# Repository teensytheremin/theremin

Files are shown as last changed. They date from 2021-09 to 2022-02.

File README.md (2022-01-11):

# Teensy Theremin

Teensy 4.1 MCU based Digital Theremin

This project is aimed to design of simple but good DIY digital [theremin](https://en.wikipedia.org/wiki/Theremin) based on microcontroller and FPGAs.

Cabinet render

Project's documentation is available on [Github Pages](https://teensytheremin.github.io/theremin/)

Component placement

PCB render

## Licensing

This is open source open hardware project.

You can freely build device using instructions for personal usage, but cannot sell it.

Firmware is licensed under GPL v2 license.

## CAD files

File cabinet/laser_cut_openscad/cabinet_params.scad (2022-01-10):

pcb_width=60.96;
pcb_length=210.82;
pcb_thickness=1.6;

cabinet_length=420;
cabinet_height=44;

panel_width=120;
panel_height=cabinet_height*0.65;
panel_rounding=panel_height/2-1;
panel_thickness=1;
panel_extra_space=0.3;
front_panel_offset_y = -2;
rear_panel_offset_y = -2;

mic_stand_mount_height = 18.288; // 0.72

cabinet_width=pcb_width + panel_thickness*2 + panel_extra_space*2;

sheet_thickness=4;

edge_extra=5;
edge_rounding=3;

ray_correction=-0.1;


// destance between volume antenna ends
volume_antenna_mount_delta=87;


// laser cut parts mounting spikes dimensions
spike_width = 16;
spike_height = sheet_thickness + edge_rounding + 0.5;


pcb_dy = -12;
pcb_mount_h = cabinet_height/2 + pcb_dy; // - pcb_thickness;
pcb_mount_offset = panel_thickness + panel_extra_space;
pcb_mount_width = spike_width + 10;


holder_angle=30;
holder_front_extra=50;


inductor_mount_wall_dist = 1;

inductor_frame_d = 32;
inductor_frame_internal_d = 20;
inductor_mount_spring_thickness = 2.2;
inductor_mount_spring_angle = 13;

volume_inductor_offset = 44;
volume_inductor_winding_len=45;

pitch_inductor_offset = inductor_frame_d/2 + inductor_mount_spring_thickness*2; //cabinet_height/2 + 1;
pitch_inductor_side_offset = 25-sheet_thickness;

pitch_inductor_length = 51;
pitch_inductor_winding_len=35;



sensor_pcb_length=35.56 - 2.54*2 + 2.54;
//sensor_pcb_length=33.02;
//sensor_pcb_width=25.4;
//sensor_pcb_width=22.86;
sensor_pcb_width=20.32;

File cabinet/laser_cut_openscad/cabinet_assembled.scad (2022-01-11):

use <cabinet_bottom.scad>
use <cabinet_top.scad>
use <cabinet_side.scad>
use <cabinet_front.scad>
use <cabinet_tablet_mount.scad>
use <pitch_antenna.scad>
use <volume_antenna.scad>
use <mic_stand_mount.scad>
use <inductor_ppl_frame.scad>
use <theremin_pcb.scad>
include <cabinet_params.scad>

module tablet_landscape(w=204,h=137.4,t=14.2) {
    translate([0,h/2,0]) linear_extrude(t)
    rounded_rectangle(w,h,5);
}

module tablet_portrait(w=204,h=137.4,t=14.2) {
    translate([0,w/2,0]) linear_extrude(t)
    rounded_rectangle(h,w,5);
}

module pcb_mounts(pcb_mount_offset=0) {
        mount_hole_r = 1.65;
        mount_hole_edge_offset = 2.54;
        dx1 = 40.64;
        dx2 = 55.88;
    // front
    translate([-dx2,-pcb_width/2+pcb_mount_offset,-cabinet_height/2]) pcb_mount(pcb_mount_h=pcb_mount_h, sheet_thickness=sheet_thickness, pcb_mount_width=pcb_mount_width, spike_width = spike_width, spike_height = spike_height, edge_rounding=edge_rounding);
    translate([dx1,-pcb_width/2+pcb_mount_offset,-cabinet_height/2]) pcb_mount(pcb_mount_h=pcb_mount_h, sheet_thickness=sheet_thickness, pcb_mount_width=pcb_mount_width, spike_width = spike_width, spike_height = spike_height, edge_rounding=edge_rounding);
    // rear
    translate([dx2,pcb_width/2-pcb_mount_offset,-cabinet_height/2]) rotate([0,0,180]) pcb_mount(pcb_mount_h=pcb_mount_h, sheet_thickness=sheet_thickness, pcb_mount_width=pcb_mount_width, spike_width = spike_width, spike_height = spike_height, edge_rounding=edge_rounding);
    translate([-dx1,pcb_width/2-pcb_mount_offset,-cabinet_height/2]) rotate([0,0,180]) pcb_mount(pcb_mount_h=pcb_mount_h, sheet_thickness=sheet_thickness, pcb_mount_width=pcb_mount_width, spike_width = spike_width, spike_height = spike_height, edge_rounding=edge_rounding);
    // left
    translate([-pcb_length/2,0,-cabinet_height/2]) rotate([0,0,-90]) pcb_mount(pcb_mount_h=pcb_mount_h, sheet_thickness=sheet_thickness, pcb_mount_width=pcb_mount_width, spike_width = spike_width, spike_height = spike_height, edge_rounding=edge_rounding);
    // right
    translate([pcb_length/2,0,-cabinet_height/2]) rotate([0,0,90]) pcb_mount(pcb_mount_h=pcb_mount_h, sheet_thickness=sheet_thickness, pcb_mount_width=pcb_mount_width, spike_width = spike_width, spike_height = spike_height, edge_rounding=edge_rounding);
}

module cabinet_assembled() {

    // bottom
    translate([0,0, -cabinet_height / 2 - sheet_thickness/2]) cabinet_bottom(cabinet_length=cabinet_length, cabinet_width=cabinet_width, cabinet_height=cabinet_height, sheet_thickness=sheet_thickness, edge_extra=edge_extra, edge_rounding=edge_rounding, ray_correction=ray_correction, spike_width=spike_width, spike_height=spike_height,  volume_inductor_offset=volume_inductor_offset, inductor_mount_wall_dist = inductor_mount_wall_dist, pitch_inductor_offset = pitch_inductor_offset,
pitch_inductor_length = pitch_inductor_length, pitch_inductor_side_offset=pitch_inductor_side_offset, pcb_length=pcb_length);

    // top
    translate([0,0, cabinet_height / 2 + sheet_thickness/2]) cabinet_top(cabinet_length=cabinet_length, cabinet_width=cabinet_width, cabinet_height=cabinet_height, sheet_thickness=sheet_thickness, edge_extra=edge_extra, edge_rounding=edge_rounding, ray_correction=ray_correction, spike_width=spike_width, spike_height=spike_height);

    // left side
    translate([-cabinet_length/2-sheet_thickness/2,0,   0]) rotate([90,0,-90]) cabinet_side_left(cabinet_length=cabinet_length, cabinet_width=cabinet_width, cabinet_height=cabinet_height, sheet_thickness=sheet_thickness, edge_extra=edge_extra, edge_rounding=edge_rounding, ray_correction=ray_correction, spike_width=spike_width, spike_height=spike_height, mic_stand_mount_height = mic_stand_mount_height);

    // right side
    translate([+cabinet_length/2+sheet_thickness/2,0,0]) rotate([90,0,90]) cabinet_side_right(cabinet_length=cabinet_length, cabinet_width=cabinet_width, cabinet_height=cabinet_height, sheet_thickness=sheet_thickness, edge_extra=edge_extra, edge_rounding=edge_rounding, ray_correction=ray_correction, spike_width=spike_width, spike_height=spike_height, mic_stand_mount_height = mic_stand_mount_height);

    // front
     translate([0,-cabinet_width/2 - sheet_thickness/2, 0]) rotate([90,0,0]) cabinet_front(cabinet_length=cabinet_length, cabinet_width=cabinet_width, cabinet_height=cabinet_height, sheet_thickness=sheet_thickness, edge_extra=edge_extra, edge_rounding=edge_rounding, ray_correction=ray_correction, panel_width=panel_width, panel_height=panel_height, panel_rounding=panel_rounding,
    panel_offset_y = front_panel_offset_y,
    spike_width=spike_width, spike_height=spike_height);

    // back
    translate([0,cabinet_width/2 + sheet_thickness/2, 0]) rotate([90,0,0]) cabinet_back(cabinet_length=cabinet_length, cabinet_width=cabinet_width, cabinet_height= cabinet_height, sheet_thickness=sheet_thickness, edge_extra=edge_extra, edge_rounding=edge_rounding, ray_correction=ray_correction, panel_width=panel_width, panel_height=panel_height, panel_rounding=panel_rounding, panel_offset_y = rear_panel_offset_y,
spike_width=spike_width, spike_height=spike_height);
    
    
    // tablet holders
    long_side_spike_count = 4;
    tablet_mount_offset = cabinet_length/long_side_spike_count/2;
    
    // left holder
    translate([-tablet_mount_offset,0,cabinet_height/2+sheet_thickness]) rotate([90,0,-90]) cabinet_tablet_mount(cabinet_length=cabinet_length, cabinet_width=cabinet_width, cabinet_height=cabinet_height, sheet_thickness=sheet_thickness, edge_extra=edge_extra, edge_rounding=edge_rounding, ray_correction=ray_correction, angle=holder_angle, spike_width = spike_width, spike_height = spike_height, front_extra=holder_front_extra);
    
    // right holder
    translate([tablet_mount_offset,0,cabinet_height/2+sheet_thickness]) rotate([90,0,-90]) cabinet_tablet_mount(cabinet_length=cabinet_length, cabinet_width=cabinet_width, cabinet_height=cabinet_height, sheet_thickness=sheet_thickness, edge_extra=edge_extra, edge_rounding=edge_rounding, ray_correction=ray_correction, angle=holder_angle, spike_width = spike_width, spike_height = spike_height, front_extra=holder_front_extra);

    
    // volume inductor mount
    translate([-cabinet_length/2+volume_inductor_offset, cabinet_width/2-sheet_thickness/2-inductor_mount_wall_dist,0]) inductor_mount(cabinet_height=cabinet_height, sheet_thickness=sheet_thickness, ray_correction=ray_correction, spike_width = spike_width, spike_height = spike_height, edge_rounding=edge_rounding, frame_d=inductor_frame_d, spring_thickness=inductor_mount_spring_thickness, spring_angle=inductor_mount_spring_angle);
    
    translate([-cabinet_length/2+volume_inductor_offset, -(cabinet_width/2-sheet_thickness/2)+inductor_mount_wall_dist,0]) inductor_mount(cabinet_height=cabinet_height, sheet_thickness=sheet_thickness, ray_correction=ray_correction, spike_width = spike_width, spike_height = spike_height, edge_rounding=edge_rounding, frame_d=inductor_frame_d, spring_thickness=inductor_mount_spring_thickness, spring_angle=inductor_mount_spring_angle);

    // pitch inductor mount
         translate([cabinet_length/2-sheet_thickness/2-inductor_mount_wall_dist-pitch_inductor_side_offset, -cabinet_width/2+pitch_inductor_offset,0]) rotate([0,0,90]) {
        inductor_mount(cabinet_height=cabinet_height, sheet_thickness=sheet_thickness, ray_correction=ray_correction, spike_width = spike_width, spike_height = spike_height, edge_rounding=edge_rounding, frame_d=inductor_frame_d, spring_thickness=inductor_mount_spring_thickness, spring_angle=inductor_mount_spring_angle);
        translate([0,-sheet_thickness,0]) inductor_mount_side(cabinet_height=cabinet_height, sheet_thickness=sheet_thickness, ray_correction=ray_correction, spike_width = spike_width, spike_height = spike_height, edge_rounding=edge_rounding, frame_d=inductor_frame_d, spring_thickness=inductor_mount_spring_thickness, spring_angle=inductor_mount_spring_angle);
    }
    translate([cabinet_length/2+sheet_thickness/2-inductor_mount_wall_dist - pitch_inductor_length-pitch_inductor_side_offset, -cabinet_width/2+pitch_inductor_offset,0]) rotate([0,0,90]) {
        inductor_mount(cabinet_height=cabinet_height, sheet_thickness=sheet_thickness, ray_correction=ray_correction, spike_width = spike_width, spike_height = spike_height, edge_rounding=edge_rounding, frame_d=inductor_frame_d, spring_thickness=inductor_mount_spring_thickness, spring_angle=inductor_mount_spring_angle);
        translate([0,sheet_thickness,0]) inductor_mount_side(cabinet_height=cabinet_height, sheet_thickness=sheet_thickness, ray_correction=ray_correction, spike_width = spike_width, spike_height = spike_height, edge_rounding=edge_rounding, frame_d=inductor_frame_d, spring_thickness=inductor_mount_spring_thickness, spring_angle=inductor_mount_spring_angle);
    }
}
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

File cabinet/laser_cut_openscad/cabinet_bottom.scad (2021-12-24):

include <rounded_rectangle.scad>

module cabinet_bottom_flat(cabinet_length=400, cabinet_width=63, cabinet_height=40, sheet_thickness=5, edge_extra=5, edge_rounding=3, ray_correction=0.1, spike_width = 15, spike_height = 9, volume_inductor_offset=32, inductor_mount_wall_dist = 0.1, pitch_inductor_offset = 24,
pitch_inductor_length = 50,     pitch_inductor_side_offset=12, pcb_width=60.96, pcb_length=210.82) {
    
    // full dimensions
    w = cabinet_length + sheet_thickness*2 + edge_extra*2;
    h = cabinet_width + sheet_thickness*2 + edge_extra*2;
    
    //echo(spike_width=spike_width, spike_height=spike_height, edge_rounding=edge_rounding);
    long_side_spike_count = 4;
    difference() {
        // main shape
        square([cabinet_length, h], center=true);
        //rounded_rectangle(w, h, edge_rounding);
        // top and bottom edge holes
        for (i = [0 : long_side_spike_count-1]) {
            index = i - (long_side_spike_count-1) / 2;
            // bottom hole
            translate([cabinet_length/long_side_spike_count*index, -cabinet_width/2-sheet_thickness/2, 0]) square([spike_width-ray_correction*2, sheet_thickness-ray_correction*2], center=true);
            translate([cabinet_length/long_side_spike_count*index, cabinet_width/2+sheet_thickness/2, 0]) square([spike_width-ray_correction*2, sheet_thickness-ray_correction*2], center=true);
        }
        // volume inductor mount holes
        translate([-cabinet_length/2+volume_inductor_offset, -cabinet_width/2+sheet_thickness/2+inductor_mount_wall_dist, 0]) square([spike_width/2-ray_correction*2, sheet_thickness-ray_correction*2], center=true);
        translate([-cabinet_length/2+volume_inductor_offset, +cabinet_width/2-sheet_thickness/2-inductor_mount_wall_dist, 0]) square([spike_width/2-ray_correction*2, sheet_thickness-ray_correction*2], center=true);
        // pitch inductor mount holes
        translate([cabinet_length/2-inductor_mount_wall_dist+sheet_thickness*0-pitch_inductor_side_offset, -cabinet_width/2+pitch_inductor_offset, 0]) square([sheet_thickness*2-ray_correction*2, spike_width/2-ray_correction*2], center=true);
        translate([cabinet_length/2-inductor_mount_wall_dist+sheet_thickness*0-pitch_inductor_length-pitch_inductor_side_offset, -cabinet_width/2+pitch_inductor_offset, 0]) square([sheet_thickness*2-ray_correction*2, spike_width/2-ray_correction*2], center=true);
        
        // Atlas Sound AD-11B mic stand flange adapter mounting holes
        mounting_r = 31.75 / 2; // 1.25" / 2
        mounting_hole_r = 4.318 / 2; // 0.17" / 2
        rotate([0, 0, 0]) translate([0, -mounting_r, 0]) circle(r = mounting_hole_r);
        rotate([0, 0, 120]) translate([0, -mounting_r, 0]) circle(r = mounting_hole_r);
        rotate([0, 0, -120]) translate([0, -mounting_r, 0]) circle(r = mounting_hole_r);

        // PCB mount
        mount_hole_r = 1.65;
        mount_hole_edge_offset = 2.54;
        dx1 = 40.64;
        dx2 = 55.88;
        // front pcb mount holes
        translate([-dx2-spike_width/4+ray_correction, -pcb_width/2+ray_correction, 0]) square([spike_width/2-ray_correction*2, sheet_thickness*2-ray_correction*2]); 
        translate([dx1-spike_width/4+ray_correction, -pcb_width/2+ray_correction, 0])square([spike_width/2-ray_correction*2, sheet_thickness*2-ray_correction*2]); 
        // rear pcb mount holes
        translate([dx2-spike_width/4+ray_correction, pcb_width/2-sheet_thickness*2+ray_correction, 0])square([spike_width/2-ray_correction*2, sheet_thickness*2-ray_correction*2]); 
        translate([-dx1-spike_width/4+ray_correction, pcb_width/2-sheet_thickness*2+ray_correction, 0])square([spike_width/2-ray_correction*2, sheet_thickness*2-ray_correction*2]); 
        // left pcb mount hole
        translate([-pcb_length/2+ray_correction, -spike_width/4+ray_correction, 0])square([sheet_thickness*2-ray_correction*2, spike_width/2-ray_correction*2]); 
        // right pcb mount hole
        translate([pcb_length/2-sheet_thickness*2+ray_correction, -spike_width/4+ray_correction, 0]) square([sheet_thickness*2-ray_correction*2, spike_width/2-ray_correction*2]); 

        // test spike positions
        //square([cabinet_length-1, cabinet_width-1], center=true);
    }
    // left edge spikes
    translate([-cabinet_length/2-spike_height/2, -h/2 + spike_width/2, 0]) rounded_spike_left(width=spike_width, height=spike_height, radius=edge_rounding);
    translate([-cabinet_length/2-spike_height/2, h/2 - spike_width/2, 0]) rounded_spike_left(width=spike_width, height=spike_height, radius=edge_rounding); 
    translate([-cabinet_length/2-spike_height/2, 0, 0]) rounded_spike_left(width=spike_width, height=spike_height, radius=edge_rounding);
    // right edge spikes
    translate([cabinet_length/2+spike_height/2, -h/2 + spike_width/2, 0]) rounded_spike_right(width=spike_width, height=spike_height, radius=edge_rounding);
    translate([cabinet_length/2+spike_height/2, h/2 - spike_width/2, 0]) rounded_spike_right(width=spike_width, height=spike_height, radius=edge_rounding);
    translate([cabinet_length/2+spike_height/2, 0, 0]) rounded_spike_right(width=spike_width, height=spike_height, radius=edge_rounding);
    
}

//cabinet_bottom_flat();

module cabinet_bottom(cabinet_length=400, cabinet_width=63, cabinet_height=40, sheet_thickness=5, edge_extra=5, edge_rounding=4, ray_correction=0.1, spike_width = 16, spike_height = 9, volume_inductor_offset=32, inductor_mount_wall_dist = 0.1, pitch_inductor_offset = 24,
pitch_inductor_length = 50, pitch_inductor_side_offset=12, pcb_width=60.96, pcb_length=210.82) {
    translate([0,0,-sheet_thickness/2]) linear_extrude(sheet_thickness)
        cabinet_bottom_flat(cabinet_length=cabinet_length, cabinet_width=cabinet_width, cabinet_height=cabinet_height, sheet_thickness=sheet_thickness, edge_extra=edge_extra, edge_rounding=edge_rounding, ray_correction=ray_correction, spike_width=spike_width, spike_height=spike_height, volume_inductor_offset=volume_inductor_offset, inductor_mount_wall_dist = inductor_mount_wall_dist, pitch_inductor_offset = pitch_inductor_offset,
pitch_inductor_length = pitch_inductor_length,  pitch_inductor_side_offset=pitch_inductor_side_offset, pcb_width=pcb_width, pcb_length=pcb_length);
}

module pcb_mount_flat(pcb_mount_h=40/2-8, sheet_thickness=5, pcb_mount_width=25, spike_width = 16, spike_height = 9, edge_rounding=4) {
    
    polygon([[-pcb_mount_width/2,0], 
    [-pcb_mount_width/2,pcb_mount_h/3], 
    [-pcb_mount_width/4,pcb_mount_h], [pcb_mount_width/4,pcb_mount_h], 
    [pcb_mount_width/2,pcb_mount_h/3], 
    [pcb_mount_width/2,0]]);
    
    //translate([-pcb_mount_width/2,0,0]) square([pcb_mount_width, pcb_mount_h]);
    translate([0,-spike_height/2,0]) rounded_spike_down(width=spike_width/2, height=spike_height, radius=edge_rounding/2);
}

//pcb_mount_flat();

module pcb_mount(pcb_mount_h=40/2-8, sheet_thickness=5, pcb_mount_width=20, spike_width = 16, spike_height = 9, edge_rounding=4) {
    difference() {
        rotate([-90,180,0]) {
            linear_extrude(sheet_thickness)
            pcb_mount_flat(pcb_mount_h=pcb_mount_h, sheet_thickness=sheet_thickness, pcb_mount_width=pcb_mount_width, spike_width = spike_width, spike_height = spike_height, edge_rounding=edge_rounding);
            translate([0,0,sheet_thickness+0.1]) linear_extrude(sheet_thickness)
            pcb_mount_flat(pcb_mount_h=pcb_mount_h, sheet_thickness=sheet_thickness, pcb_mount_width=pcb_mount_width, spike_width = spike_width, spike_height = spike_height, edge_rounding=edge_rounding);
        }
        translate([0,2.54,pcb_mount_h+0.1-8]) cylinder(h=8, d=2);
    }
}

//pcb_mount();

//cabinet_bottom();

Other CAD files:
cabinet/laser_cut_openscad/cabinet_front.scad
cabinet/laser_cut_openscad/cabinet_laser_cut.scad
cabinet/laser_cut_openscad/cabinet_side.scad
cabinet/laser_cut_openscad/cabinet_tablet_mount.scad
cabinet/laser_cut_openscad/cabinet_top.scad
cabinet/laser_cut_openscad/inductor_ppl_frame.scad
cabinet/laser_cut_openscad/mic_stand_mount.scad
cabinet/laser_cut_openscad/mounts_and_fittings.scad
cabinet/laser_cut_openscad/panels_laser_cut.scad
cabinet/laser_cut_openscad/pitch_antenna.scad
cabinet/laser_cut_openscad/rounded_rectangle.scad
cabinet/laser_cut_openscad/theremin_pcb.scad
cabinet/laser_cut_openscad/volume_antenna.scad

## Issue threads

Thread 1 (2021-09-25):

I am very interested in this project. How is the completion of this project?

ws786873, 2021-09-25:
I am very interested in this project. How is the completion of this project?

buggins, 2021-12-20:
Project is in progress.
Forum thread: http://thereminworld.com/Forums/T/32640/teensy-40-600mhz-arm-cortex-m-7-mcu---ideal-for-digital-mcu-based-theremin

ws786873, 2022-01-08:
> 项目正在进行中。 论坛主题：[http](http://thereminworld.com/Forums/T/32640/teensy-40-600mhz-arm-cortex-m-7-mcu---ideal-for-digital-mcu-based-theremin) : [//thereminworld.com/Forums/T/32640/teensy-40-600mhz-arm-cortex-m-7-mcu---ideal-for-digital-mcu-based-theremin](http://thereminworld.com/Forums/T/32640/teensy-40-600mhz-arm-cortex-m-7-mcu---ideal-for-digital-mcu-based-theremin)

Looks like it's going well. Come on. If the design is complete, I want to try to build it first.

buggins, 2022-01-10:
Hi!

Design is in progress.
Cabinet + PCBs design : almost ready.
Android app, android to teensy USB communication - connect/disconnect is
visible, not yet managed to transmit data via USB serial.
Teensy MCU app: simple synthesizer with varying volume and pitch

I think it makes sense to try building once minimal implementation is
working - when it can produce sound controlled by sensing of antennas.

сб, 8 янв. 2022 г. в 17:02, ws786873 ***@***.***>:

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

--
Best regards,
    Vadim

ws786873, 2022-03-16:
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

Hi, nice to see your software update in the forum. So in terms of hardware, can it realize basic performance? I can't wait to try to build it

buggins, 2022-03-16:
not ready yet.
You will see demo on thereminworld forum, once it becomes playable

ср, 16 мар. 2022 г. в 18:38, ws786873 ***@***.***>:

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

--
Best regards,
    Vadim

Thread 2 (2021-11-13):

Вопрос по DLang

MGWL, 2021-11-13:
Илья, здравствуйте.
Извините, что пишу сюда в надежде, что вы увидите данное сообщение.
Хотелось бы узнать планируете ли ещё заниматься D, в частости IDE?
Собрать IDE текущей версией dmd мне не удаётся из за ошибок.
Буду признателен, если ответите на почту mgw@yandex.ru
Геннадий

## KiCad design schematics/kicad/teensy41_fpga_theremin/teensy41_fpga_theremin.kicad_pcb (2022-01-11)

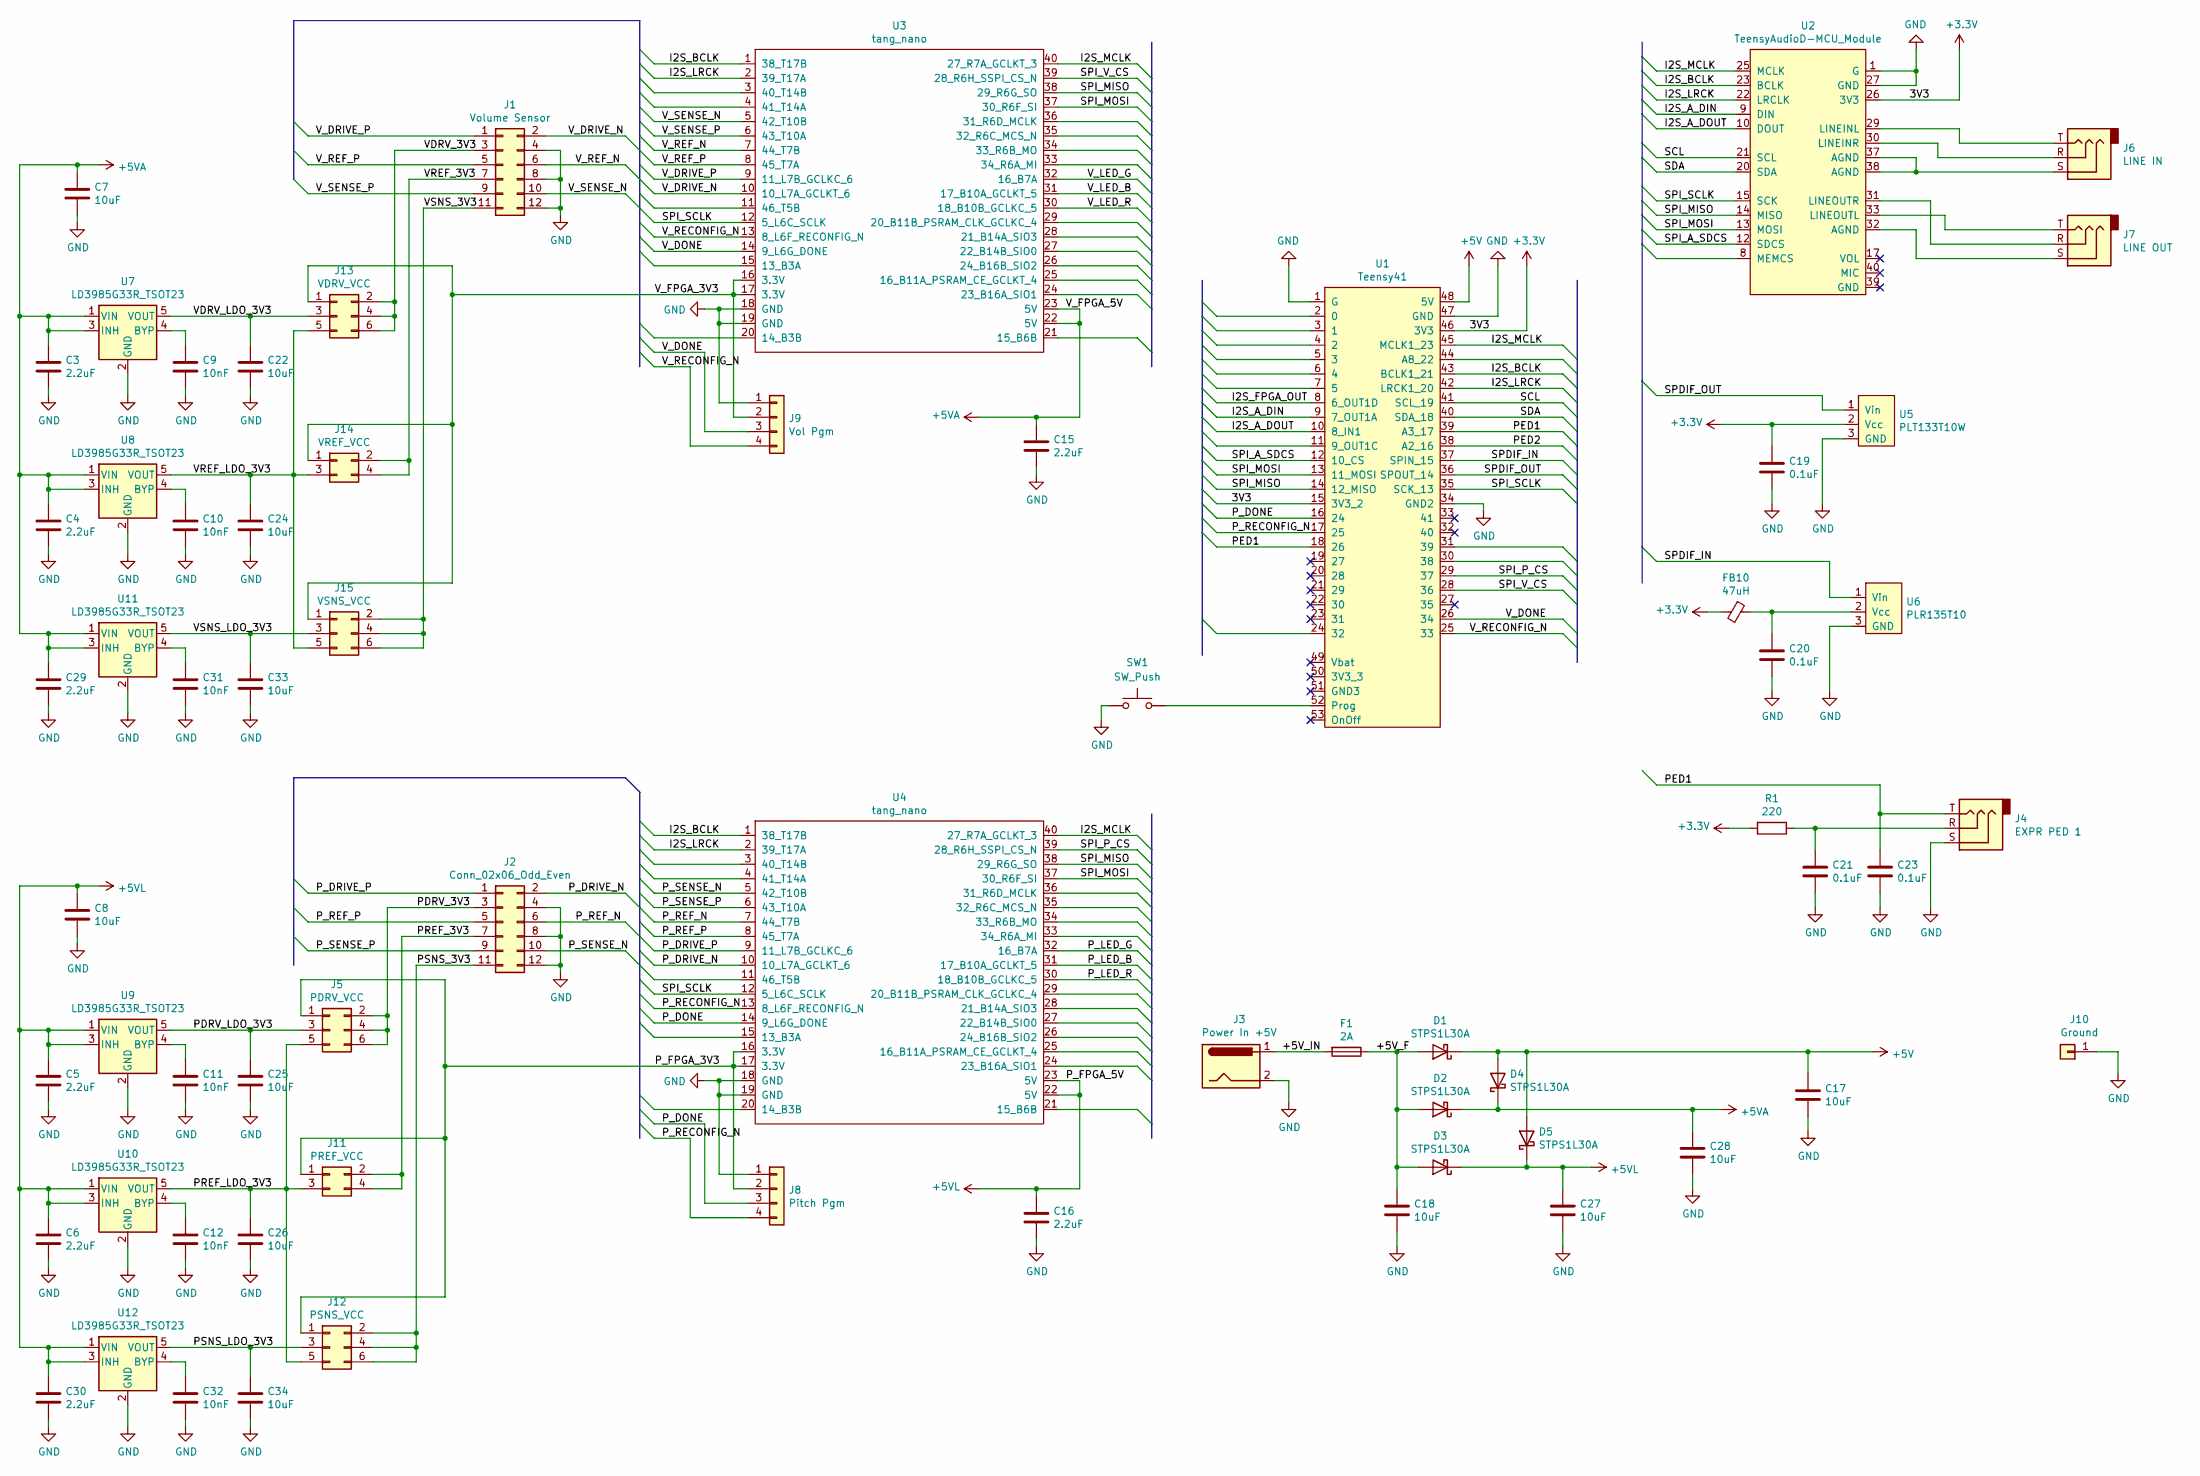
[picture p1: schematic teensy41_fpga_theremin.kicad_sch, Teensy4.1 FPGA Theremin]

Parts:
C3, C4, C5, C6, C15, C16, C29, C30: 2.2uF; C_0805_2012Metric
C7, C8, C17, C18, C22, C24, C25, C26, C27, C28, C33, C34: 10uF; C_0805_2012Metric
C9, C10, C11, C12, C31, C32: 10nF; C_0805_2012Metric
C19, C20, C21, C23: 0.1uF; C_0805_2012Metric
D1, D2, D3, D4, D5: STPS1L30A; D_SMA
F1: 2A; Fuse_1206_3216Metric
FB10: 47uH; L_1812_4532Metric
J1: Volume Sensor; PinSocket_2x06_P2.54mm_Horizontal
J2: Conn_02x06_Odd_Even; PinSocket_2x06_P2.54mm_Horizontal
J3: Power In +5V; BarrelJack_Horizontal
J4: EXPR PED 1; Jack_6.35mm_ST_008G_04
J5: PDRV_VCC; PinHeader_2x03_P2.54mm_Vertical
J6: LINE IN; Jack_3.5mm_CUI_SJ1-3533NG_Horizontal
J7: LINE OUT; Jack_6.35mm_ST_008G_04
J8: Pitch Pgm; PinHeader_1x04_P2.54mm_Vertical
J9: Vol Pgm; PinHeader_1x04_P2.54mm_Vertical
J10: Ground; PinHeader_1x01_P2.54mm_Vertical
J11: PREF_VCC; PinHeader_2x02_P2.54mm_Vertical
J12: PSNS_VCC; PinHeader_2x03_P2.54mm_Vertical
J13: VDRV_VCC; PinHeader_2x03_P2.54mm_Vertical
J14: VREF_VCC; PinHeader_2x02_P2.54mm_Vertical
J15: VSNS_VCC; PinHeader_2x03_P2.54mm_Vertical
R1: 220; R_0805_2012Metric
SW1: SW_Push; SW_Tactile_SPST_Angled_PTS645Vx58-2LFS
U1: Teensy41
U2: TeensyAudioD-MCU_Module; TeensyAudioD
U3, U4: tang_nano
U5: PLT133T10W
U6: PLR135T10; PLT133T10W
U7, U8, U9, U10, U11, U12: LD3985G33R_TSOT23; TSOT-23-5

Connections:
+3V3: C19.1, FB10.2, R1.2, U1.15 (3V3_2), U1.46 (3V3), U2.26 (3V3), U5.2 (Vcc)
+5V: C17.1, D1.1 (K), D4.2 (A), D5.2 (A), U1.48 (5V)
+5VA: C3.1, C4.1, C7.1, C15.1, C28.1, C29.1, D2.1 (K), D4.1 (K), U3.22 (5V), U3.23 (5V), U7.1 (VIN), U7.3 (INH), U8.1 (VIN), U8.3 (INH), U11.1 (VIN), U11.3 (INH)
+5VL: C5.1, C6.1, C8.1, C16.1, C27.1, C30.1, D3.1 (K), D5.1 (K), U4.22 (5V), U4.23 (5V), U9.1 (VIN), U9.3 (INH), U10.1 (VIN), U10.3 (INH), U12.1 (VIN), U12.3 (INH)
/+5V_F: C18.1, D1.2 (A), D2.2 (A), D3.2 (A), F1.1
/+5V_IN: F1.2, J3.1
/I2S_A_DIN: U1.9 (7_OUT1A), U2.9 (DIN)
/I2S_A_DOUT: U1.10 (8_IN1), U2.10 (DOUT)
/I2S_BCLK: U1.43 (BCLK1_21), U2.23 (BCLK), U3.1 (38_T17B), U4.1 (38_T17B)
/I2S_FPGA_OUT: U1.8 (6_OUT1D)
/I2S_LRCK: U1.42 (LRCK1_20), U2.22 (LRCLK), U3.2 (39_T17A), U4.2 (39_T17A)
/I2S_MCLK: U1.45 (MCLK1_23), U2.25 (MCLK), U3.40 (27_R7A_GCLKT_3), U4.40 (27_R7A_GCLKT_3)
/PDRV_3V3: J2.3, J5.2, J5.4, J5.6
/PDRV_LDO_3V3: C25.1, J5.3, U9.5 (VOUT)
/PED1: C23.1, J4.T, U1.18 (26), U1.39 (A3_17)
/PED2: U1.38 (A2_16)
/PREF_3V3: J2.7, J11.2, J11.4
/PREF_LDO_3V3: C26.1, J5.5, J11.3, J12.5, U10.5 (VOUT)
/PSNS_3V3: J2.11, J12.2, J12.4, J12.6
/PSNS_LDO_3V3: C34.1, J12.3, U12.5 (VOUT)
/P_DONE: J8.3, U1.16 (24), U4.14 (9_L6G_DONE)
/P_DRIVE_N: J2.2, U4.10 (10_L7A_GCLKT_6)
/P_DRIVE_P: J2.1, U4.9 (11_L7B_GCLKC_6)
/P_FPGA_3V3: J5.1, J8.2, J11.1, J12.1, U4.16 (3.3V), U4.17 (3.3V)
/P_LED_B: U4.31 (17_B10A_GCLKT_5)
/P_LED_G: U4.32 (16_B7A)
/P_LED_R: U4.30 (18_B10B_GCLKC_5)
/P_RECONFIG_N: J8.4, U1.17 (25), U4.13 (8_L6F_RECONFIG_N)
/P_REF_N: J2.6, U4.7 (44_T7B)
/P_REF_P: J2.5, U4.8 (45_T7A)
/P_SENSE_N: J2.10, U4.5 (42_T10B)
/P_SENSE_P: J2.9, U4.6 (43_T10A)
/SCL: U1.41 (SCL_19), U2.21 (SCL)
/SDA: U1.40 (SDA_18), U2.20 (SDA)
/SPDIF_IN: U1.37 (SPIN_15), U6.1 (Vin)
/SPDIF_OUT: U1.36 (SPOUT_14), U5.1 (Vin)
/SPI_A_SDCS: U1.12 (10_CS), U2.12 (SDCS)
/SPI_MISO: U1.14 (12_MISO), U2.14 (MISO), U3.38 (29_R6G_SO), U4.38 (29_R6G_SO)
/SPI_MOSI: U1.13 (11_MOSI), U2.13 (MOSI), U3.37 (30_R6F_SI), U4.37 (30_R6F_SI)
/SPI_P_CS: U1.29 (37), U4.39 (28_R6H_SSPI_CS_N)
/SPI_SCLK: U1.35 (SCK_13), U2.15 (SCK), U3.12 (5_L6C_SCLK), U4.12 (5_L6C_SCLK)
/SPI_V_CS: U1.28 (36), U3.39 (28_R6H_SSPI_CS_N)
/VDRV_3V3: J1.3, J13.2, J13.4, J13.6
/VDRV_LDO_3V3: C22.1, J13.3, U7.5 (VOUT)
/VREF_3V3: J1.7, J14.2, J14.4
/VREF_LDO_3V3: C24.1, J13.5, J14.3, J15.5, U8.5 (VOUT)
/VSNS_3V3: J1.11, J15.2, J15.4, J15.6
/VSNS_LDO_3V3: C33.1, J15.3, U11.5 (VOUT)
/V_DONE: J9.3, U1.26 (34), U3.14 (9_L6G_DONE)
/V_DRIVE_N: J1.2, U3.10 (10_L7A_GCLKT_6)
/V_DRIVE_P: J1.1, U3.9 (11_L7B_GCLKC_6)
/V_FPGA_3V3: J9.2, J13.1, J14.1, J15.1, U3.16 (3.3V), U3.17 (3.3V)
/V_LED_B: U3.31 (17_B10A_GCLKT_5)
/V_LED_G: U3.32 (16_B7A)
/V_LED_R: U3.30 (18_B10B_GCLKC_5)
/V_RECONFIG_N: J9.4, U1.25 (33), U3.13 (8_L6F_RECONFIG_N)
/V_REF_N: J1.6, U3.7 (44_T7B)
/V_REF_P: J1.5, U3.8 (45_T7A)
/V_SENSE_N: J1.10, U3.5 (42_T10B)
/V_SENSE_P: J1.9, U3.6 (43_T10A)
GND: C3.2, C4.2, C5.2, C6.2, C7.2, C8.2, C9.2, C10.2, C11.2, C12.2, C15.2, C16.2, C17.2, C18.2, C19.2, C20.2, C21.2, C22.2, C23.2, C24.2, C25.2, C26.2, C27.2, C28.2, C29.2, C30.2, C31.2, C32.2, C33.2, C34.2, J1.4, J1.8, J1.12, J2.4, J2.8, J2.12, J3.2, J4.S, J8.1, J9.1, J10.1, SW1.1, U1.1 (G), U1.34 (GND2), U1.47 (GND), U2.1 (G), U2.27 (GND), U3.18 (GND), U3.19 (GND), U4.18 (GND), U4.19 (GND), U5.3 (GND), U6.3 (GND), U7.2 (GND), U8.2 (GND), U9.2 (GND), U10.2 (GND), U11.2 (GND), U12.2 (GND)
unnamed: C9.1, U7.4 (BYP)
unnamed: C10.1, U8.4 (BYP)
unnamed: C11.1, U9.4 (BYP)
unnamed: C12.1, U10.4 (BYP)
unnamed: C20.1, FB10.1, U6.2 (Vcc)
unnamed: C21.1, J4.R, R1.1
unnamed: C31.1, U11.4 (BYP)
unnamed: C32.1, U12.4 (BYP)
unnamed: J6.R, U2.30 (LINEINR)
unnamed: J6.S, U2.37 (AGND), U2.38 (AGND)
unnamed: J6.T, U2.29 (LINEINL)
unnamed: J7.R, U2.31 (LINEOUTR)
unnamed: J7.S, U2.32 (AGND)
unnamed: J7.T, U2.33 (LINEOUTL)
unnamed: SW1.2, U1.52 (Prog)

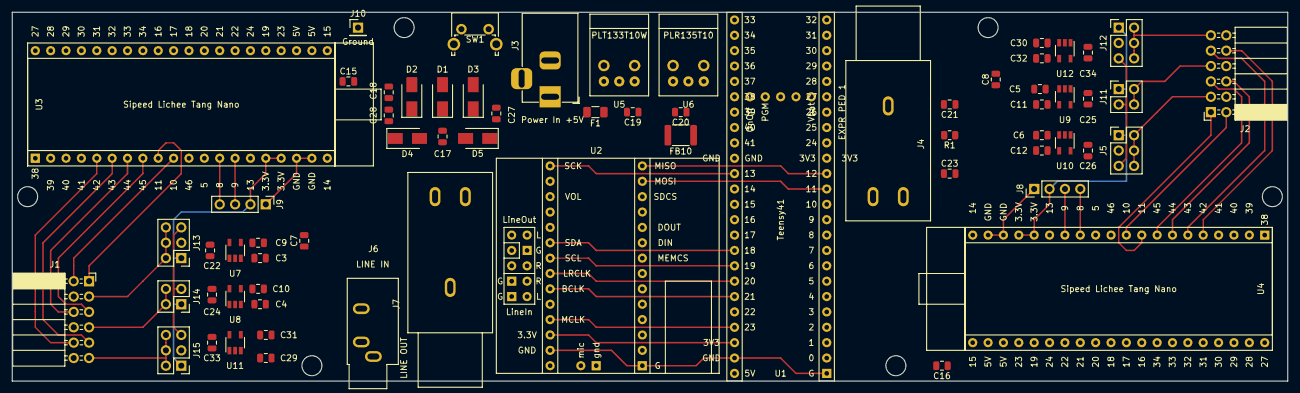
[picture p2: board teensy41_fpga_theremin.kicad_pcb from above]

Board: 2 copper layers, 210.8 x 61.0 mm, 66 parts (0 on the bottom side), 68 nets.

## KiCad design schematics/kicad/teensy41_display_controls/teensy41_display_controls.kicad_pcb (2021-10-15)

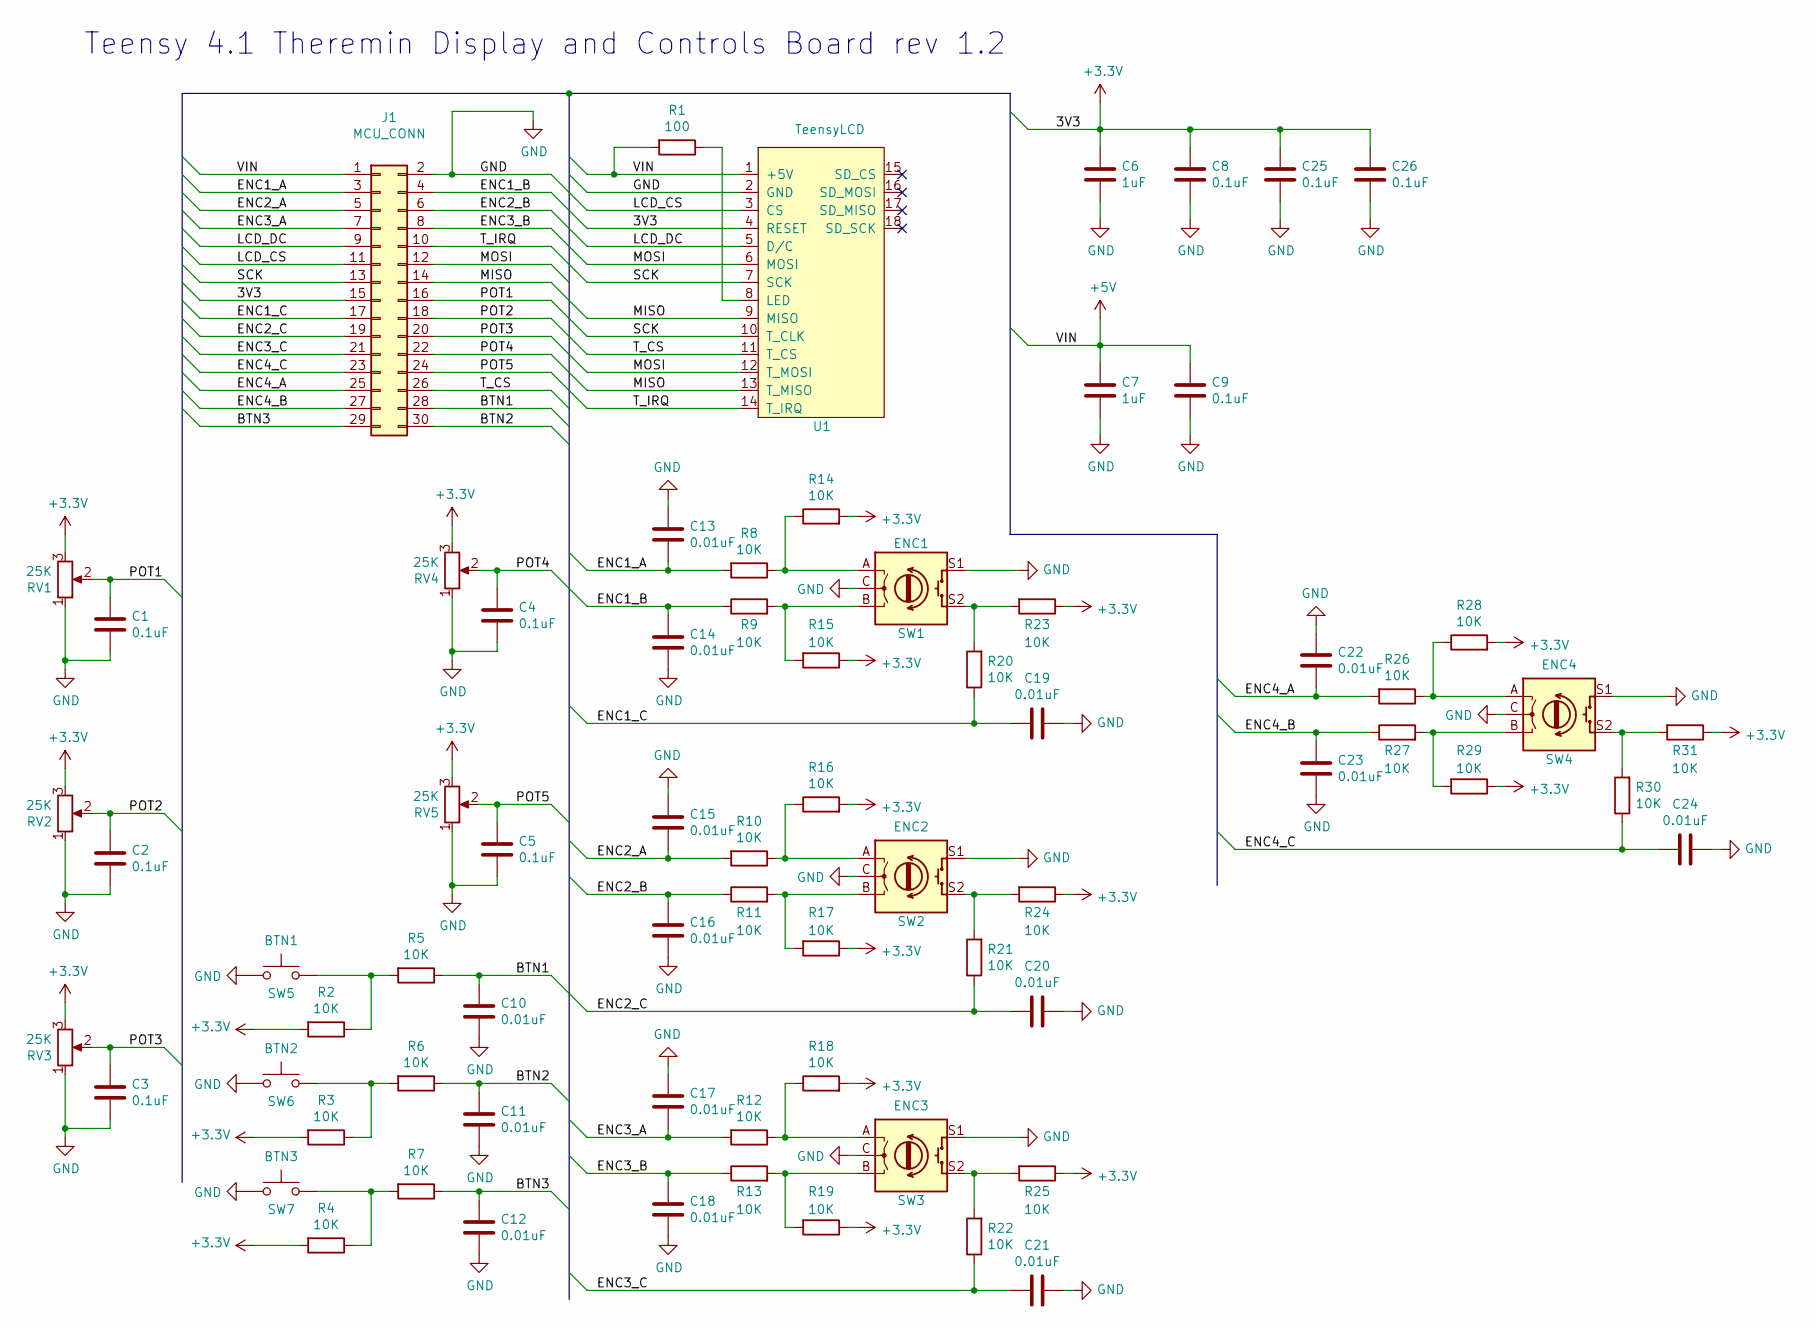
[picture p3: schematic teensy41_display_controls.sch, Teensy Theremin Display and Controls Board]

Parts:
C1, C2, C3, C4, C5, C8, C9, C25, C26: 0.1uF; C_0805_2012Metric_Pad1.18x1.45mm_HandSolder
C6, C7: 1uF; C_0805_2012Metric_Pad1.18x1.45mm_HandSolder
C10, C11, C12, C13, C14, C15, C16, C17, C18, C19, C20, C21, C22, C23, C24: 0.01uF; C_0805_2012Metric_Pad1.18x1.45mm_HandSolder
J1: MCU_CONN; IDC-Header_2x15_P2.54mm_Vertical
R1: 100; R_0805_2012Metric_Pad1.20x1.40mm_HandSolder
R2, R3, R4, R5, R6, R7, R8, R9, R10, R11, R12, R13, R14, R15, R16, R17, R18, R19, R20, R21, R22, R23, R24, R25, R26, R27, R28, R29, R30, R31: 10K; R_0805_2012Metric_Pad1.20x1.40mm_HandSolder
RV1, RV2, RV3, RV4, RV5: 25K; Potentiometer_TT_P0915N
SW1: ENC1; RotaryEncoder_Alps_EC11E-Switch_Vertical_H20mm
SW2: ENC2; RotaryEncoder_Alps_EC11E-Switch_Vertical_H20mm
SW3: ENC3; RotaryEncoder_Alps_EC11E-Switch_Vertical_H20mm
SW4: ENC4; RotaryEncoder_Alps_EC11E-Switch_Vertical_H20mm
SW5: BTN1; SW_PUSH_6mm_H9.5mm
SW6: BTN2; SW_PUSH_6mm_H9.5mm
SW7: BTN3; SW_PUSH_6mm_H9.5mm
U1: TeensyLCD; TeensyLCD_ILI9341

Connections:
+3V3: C6.1, C8.1, C25.1, C26.1, J1.15, R2.2, R3.2, R4.2, R14.2, R15.1, R16.2, R17.1, R18.2, R19.1, R23.1, R24.1, R25.1, R28.2, R29.1, R31.1, RV1.3, RV2.3, RV3.3, RV4.3, RV5.3, U1.4 (RESET)
+5V: C7.1, C9.1, J1.1, R1.2, U1.1 (+5V)
/BTN1: C10.1, J1.28, R5.1
/BTN2: C11.1, J1.30, R6.1
/BTN3: C12.1, J1.29, R7.1
/ENC1_A: C13.2, J1.3, R8.2
/ENC1_B: C14.1, J1.4, R9.1
/ENC1_C: C19.2, J1.17, R20.1
/ENC2_A: C15.2, J1.5, R10.2
/ENC2_B: C16.1, J1.6, R11.1
/ENC2_C: C20.2, J1.19, R21.1
/ENC3_A: C17.2, J1.7, R12.2
/ENC3_B: C18.1, J1.8, R13.1
/ENC3_C: C21.2, J1.21, R22.1
/ENC4_A: C22.2, J1.25, R26.2
/ENC4_B: C23.1, J1.27, R27.1
/ENC4_C: C24.2, J1.23, R30.1
/LCD_CS: J1.11, U1.3 (CS)
/LCD_DC: J1.9, U1.5 (D/C)
/MISO: J1.14, U1.9 (MISO), U1.13 (T_MISO)
/MOSI: J1.12, U1.6 (MOSI), U1.12 (T_MOSI)
/POT1: C1.1, J1.16, RV1.2
/POT2: C2.1, J1.18, RV2.2
/POT3: C3.1, J1.20, RV3.2
/POT4: C4.1, J1.22, RV4.2
/POT5: C5.1, J1.24, RV5.2
/SCK: J1.13, U1.7 (SCK), U1.10 (T_CLK)
/T_CS: J1.26, U1.11 (T_CS)
/T_IRQ: J1.10, U1.14 (T_IRQ)
GND: C1.2, C2.2, C3.2, C4.2, C5.2, C6.2, C7.2, C8.2, C9.2, C10.2, C11.2, C12.2, C13.1, C14.2, C15.1, C16.2, C17.1, C18.2, C19.1, C20.1, C21.1, C22.1, C23.2, C24.1, C25.2, C26.2, J1.2, RV1.1, RV2.1, RV3.1, RV4.1, RV5.1, SW1.C, SW1.S1, SW2.C, SW2.S1, SW3.C, SW3.S1, SW4.C, SW4.S1, SW5.1, SW6.1, SW7.1, U1.2 (GND)
unnamed: R1.1, U1.8 (LED)
unnamed: R2.1, R5.2, SW5.2
unnamed: R3.1, R6.2, SW6.2
unnamed: R4.1, R7.2, SW7.2
unnamed: R10.1, R16.1, SW2.A
unnamed: R11.2, R17.2, SW2.B
unnamed: R12.1, R18.1, SW3.A
unnamed: R13.2, R19.2, SW3.B
unnamed: R8.1, R14.1, SW1.A
unnamed: R9.2, R15.2, SW1.B
unnamed: R20.2, R23.2, SW1.S2
unnamed: R21.2, R24.2, SW2.S2
unnamed: R22.2, R25.2, SW3.S2
unnamed: R26.1, R28.1, SW4.A
unnamed: R27.2, R29.2, SW4.B
unnamed: R30.2, R31.2, SW4.S2

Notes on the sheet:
Teensy 4.1 Theremin Display and Controls Board rev 1.2

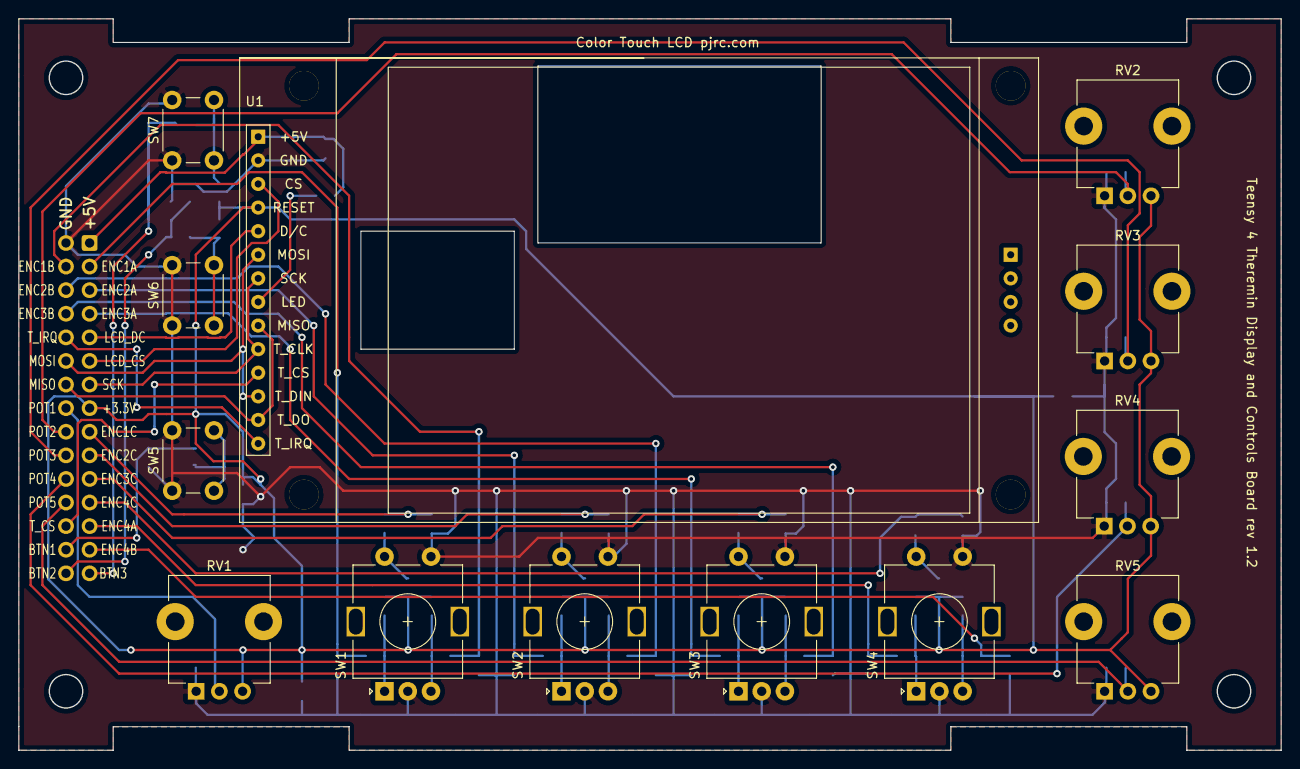
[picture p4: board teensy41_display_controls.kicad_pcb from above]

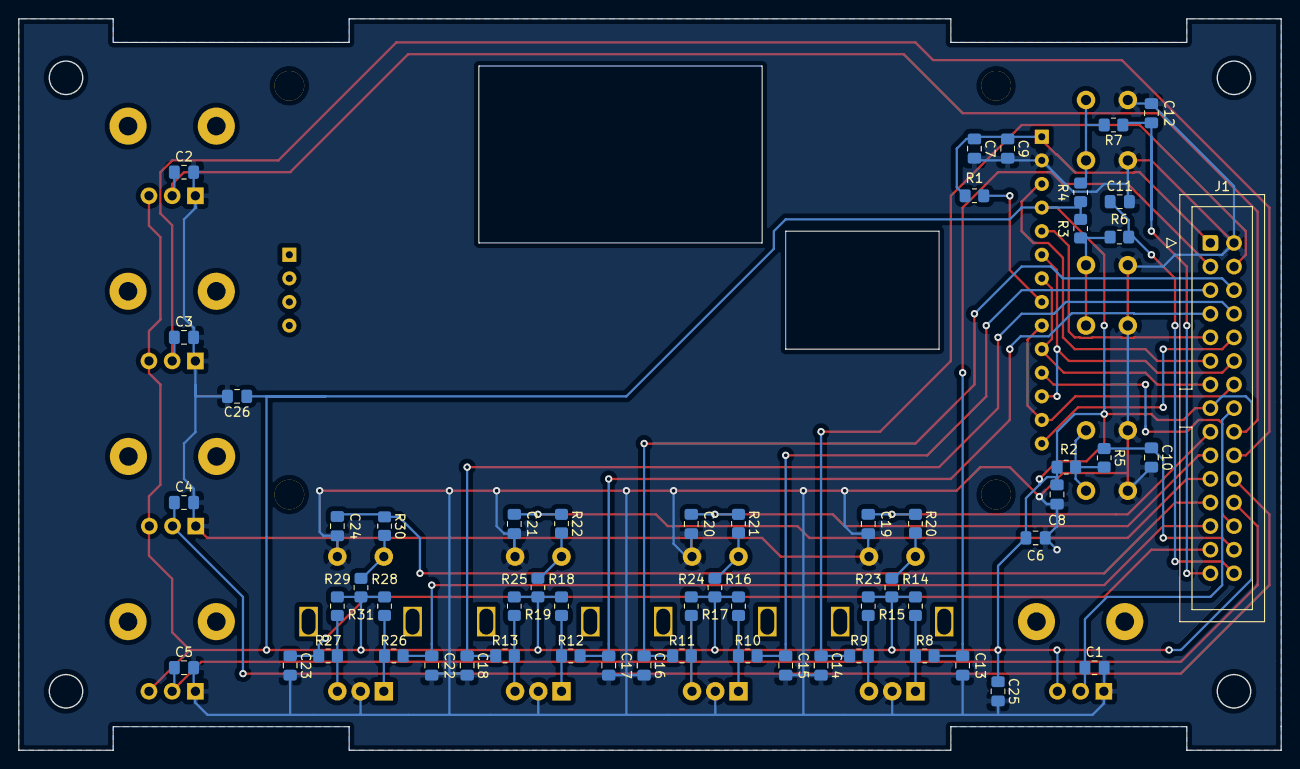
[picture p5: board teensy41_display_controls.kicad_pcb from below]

Board: 2 copper layers, 135.9 x 78.7 mm, 71 parts (58 on the bottom side), 46 nets.

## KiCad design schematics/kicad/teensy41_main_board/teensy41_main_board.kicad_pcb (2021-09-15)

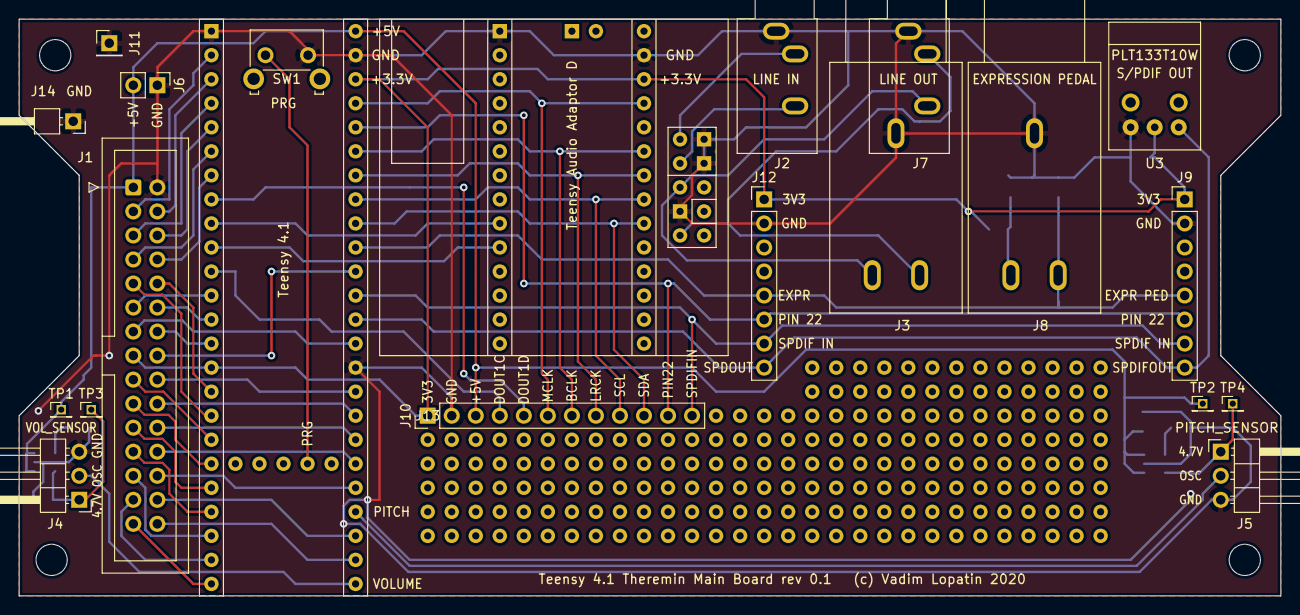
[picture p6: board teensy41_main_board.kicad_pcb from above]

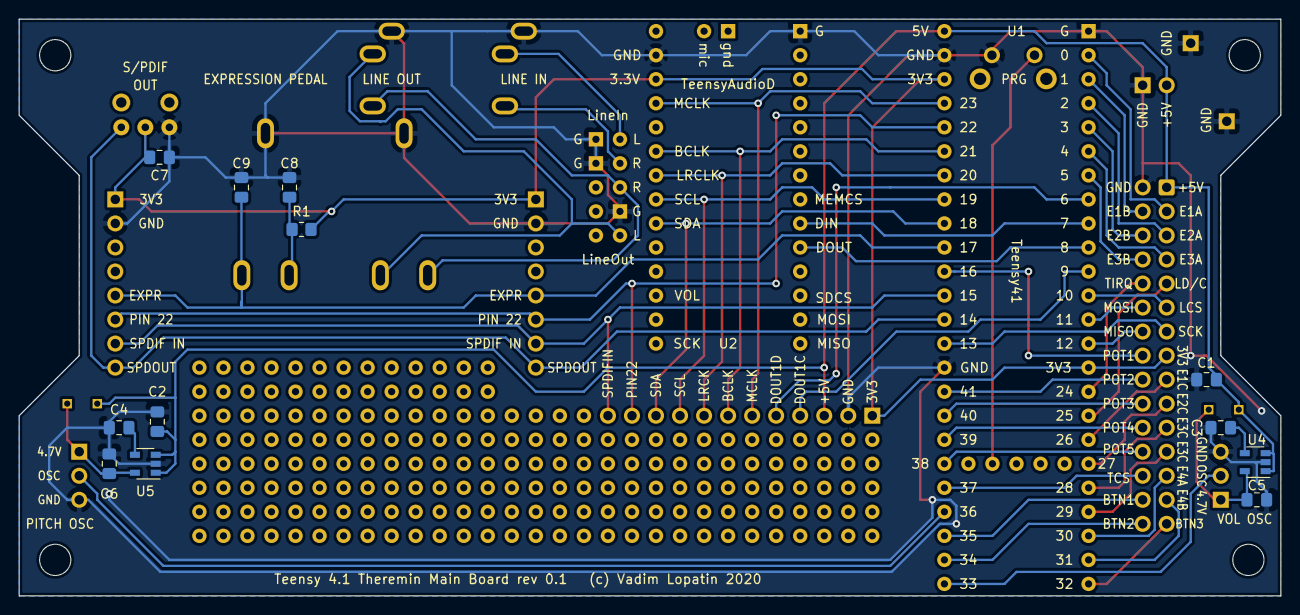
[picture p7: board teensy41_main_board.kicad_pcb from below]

Board: 2 copper layers, 133.3 x 61.0 mm, 34 parts (12 on the bottom side), 55 nets.

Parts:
C1, C2, C5, C6: 1uF; C_0805_2012Metric_Pad1.18x1.45mm_HandSolder
C3, C4: 10nF; C_0805_2012Metric_Pad1.18x1.45mm_HandSolder
C7, C8, C9: 0.1uF; C_0805_2012Metric_Pad1.18x1.45mm_HandSolder
J1: LCD_CONTROLS; IDC-Header_2x15_P2.54mm_Vertical
J2: LINE_IN; Jack_3.5mm_CUI_SJ1-3533NG_Horizontal
J3: LINE_OUT_BIG; Jack_6.35mm_ST_008G_04
J4: VOL_SENSOR; PinHeader_1x03_P2.54mm_Horizontal
J5: PITCH_SENSOR; PinHeader_1x03_P2.54mm_Horizontal
J6: POWER_IN; PinHeader_1x02_P2.54mm_Vertical
J7: LINE_OUT_35; Jack_3.5mm_CUI_SJ1-3533NG_Horizontal
J8: EXPR_PED; Jack_6.35mm_ST_008G_04
J9: SPDIF_IN; PinHeader_1x08_P2.54mm_Vertical
J10: AUDIO_OUT_EXT; PinHeader_1x12_P2.54mm_Vertical
J11: Grounding; PinHeader_1x01_P2.54mm_Vertical
J12: SPDIF_IN2; PinHeader_1x08_P2.54mm_Vertical
J13: ProtoGrid; Teensy41ThereminProtoGrid
J14: Grounding2; PinHeader_1x01_P2.54mm_Horizontal
R1: 200; R_0805_2012Metric_Pad1.20x1.40mm_HandSolder
SW1: SW_Push; SW_Tactile_SKHH_Angled
TP1: VIN1; PinHeader_1x01_P1.27mm_Vertical
TP2: VIN2; PinHeader_1x01_P1.27mm_Vertical
TP3: VCCVOL; PinHeader_1x01_P1.27mm_Vertical
TP4: VCCPITCH; PinHeader_1x01_P1.27mm_Vertical
U1: Teensy41
U2: TeensyAudioD
U3: PLT133T10W
U4, U5: LD3985M47R_SOT23; SOT-23-5

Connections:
/3V3: C7.1, J1.15, J9.1, J10.1, J12.1, R1.1, U1.15, U1.46, U2.26, U3.2
/BTN_1: J1.28, U1.27
/BTN_2: J1.30, U1.26
/BTN_3: J1.29, U1.24
/ENC1_A: J1.3, U1.2
/ENC1_B: J1.4, U1.3
/ENC1_C: J1.17, U1.18
/ENC2_A: J1.5, U1.4
/ENC2_B: J1.6, U1.5
/ENC2_C: J1.19, U1.19
/ENC3_A: J1.7, U1.6
/ENC3_B: J1.8, U1.7
/ENC3_C: J1.21, U1.20
/ENC4_A: J1.25, U1.22
/ENC4_B: J1.27, U1.23
/ENC4_C: J1.23, U1.21
/EXPR_PED: C9.1, J8.T, J9.5, J12.5, U1.39
/I2C_SCL: J10.9, U1.41, U2.21
/I2C_SDA: J10.10, U1.40, U2.20
/I2S_BCLK: J10.7, U1.43, U2.23
/I2S_DIN1: U1.10, U2.10
/I2S_DOUT1A: U1.9, U2.9
/I2S_DOUT1C: J10.4, U1.11
/I2S_DOUT1D: J10.5, U1.8
/I2S_LRCK: J10.8, U1.42, U2.22
/I2S_MCLK: J10.6, U1.45, U2.25
/LCD_CS: J1.11, U1.12
/LCD_DC: J1.9, U1.17
/LCD_MISO: J1.14, U1.14
/LCD_MOSI: J1.12, U1.13
/LCD_SCK: J1.13, U1.35
/LIN_L: J2.T, U2.29
/LIN_R: J2.R, U2.30
/LOUT_L: J3.T, J7.T, U2.33
/LOUT_R: J3.R, J7.R, U2.31
/PIN22: J9.6, J10.11, J12.6, U1.44
/PITCH_OSC: J5.2, U1.28
/POT1: J1.16, U1.38
/POT2: J1.18, U1.33
/POT3: J1.20, U1.32
/POT4: J1.22, U1.31
/POT5: J1.24, U1.30
/PROG: SW1.1, U1.52
/SPDIF_IN: J9.7, J10.12, J12.7, U1.37
/SPDIF_OUT: J9.8, J12.8, U1.36, U3.1
/TOUCH_CS: J1.26, U1.29
/TOUCH_IRQ: J1.10, U1.16
/VCC_PITCH: C6.1, J5.1, TP4.1, U5.5
/VCC_VOL: C5.1, J4.1, TP3.1, U4.5
/VIN: C1.1, C2.1, J1.1, J6.2, J10.3, TP1.1, TP2.1, U1.48, U4.1, U4.3, U5.1, U5.3
/VOL_OSC: J4.2, U1.25
GND: C1.2, C2.2, C3.2, C4.2, C5.2, C6.2, C7.2, C8.2, C9.2, J1.2, J2.S, J3.S, J4.3, J5.3, J6.1, J7.S, J8.S, J9.2, J10.2, J11.1, J12.2, J14.1, SW1.2, U1.1, U1.34, U1.47, U2.1, U2.27, U2.32, U2.37, U2.38, U3.3, U4.2, U5.2
unnamed: C3.1, U4.4
unnamed: C4.1, U5.4
unnamed: C8.1, J8.R, R1.2

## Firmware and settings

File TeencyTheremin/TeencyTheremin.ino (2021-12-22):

#include "ThereminAudio.h"

IntervalTimer pitchInputTimer;
IntervalTimer volumeInputTimer;

AudioSynthWaveformSine   sine1;         
AudioSynthWaveformSine   sine2;        
AudioOutputI2S           i2s1;           
AudioConnection          patchCord1(sine1, 0, i2s1, 0);
AudioConnection          patchCord2(sine2, 0, i2s1, 1);
ThereminAudioControlSGTL5000 codec;

const int ledPin = 13;  // the pin with a LED
bool ledOn = false;
volatile unsigned long pitchSensorValue = 22500; //mHz
volatile unsigned long volumeSensorValue = 1000000; //ppm

int regime = 1;
void simulatePitchInput() {
  
  if(regime == 1) {
    pitchSensorValue = (long) pitchSensorValue * 1.005;
  }
  if(regime == 2) { 
    pitchSensorValue = (long) pitchSensorValue * 0.995;
  }
  
  if(pitchSensorValue > 4000000){
    regime = 2;
  }
  if(pitchSensorValue < 22500){
    pitchSensorValue = 440000;
    volumeSensorValue = 10000;
    regime = 3;
  }
  
  sine1.frequency(pitchSensorValue / 1000.0);
  sine2.frequency(pitchSensorValue / 1000.0);
}
void simulateVolumeInput() {
  
  if(regime == 3) {
    volumeSensorValue = volumeSensorValue + 4000;
  }
  if(regime == 4) { 
    volumeSensorValue = volumeSensorValue - 4000;
  }
  
  if(volumeSensorValue > 1000000){
    regime = 4;
  }
  if(volumeSensorValue < 5000){
    pitchSensorValue = 22500;
    volumeSensorValue = 1000000;
    regime = 1;
  }
}

void setup()
{
  sine1.amplitude(1.0);
  sine2.amplitude(1.0);
  
  pinMode(ledPin, OUTPUT);
  pitchInputTimer.begin(simulatePitchInput, 5000);  // pitch changes every 0.005 seconds
  volumeInputTimer.begin(simulateVolumeInput, 10000);  // volume changes every 0.01 seconds
  
  Serial.begin(115200);
  //while (!Serial) ; // wait for Arduino Serial Monitor
  delay(200);
  
// http://gcc.gnu.org/onlinedocs/cpp/Standard-Predefined-Macros.html
  Serial.print("Begin ");
  Serial.println(__FILE__);
  
  // Proc = 12 (13),  Mem = 2 (8)
  // Audio connections require memory to work.
  // The memory usage code indicates that 10 is the maximum
  // so give it 12 just to be sure.
  AudioMemory(18);
  
  codec.enable();
  codec.volume(0.30);

  Serial.println("setup done");
  
  // Initialize processor and memory measurements
  AudioProcessorUsageMaxReset();
  AudioMemoryUsageMaxReset();
}

float volume;

unsigned long last_time = millis();
void loop()
{
  unsigned long pitchSensorValueCopy;  
  unsigned long volumeSensorValueCopy;

  noInterrupts();
  pitchSensorValueCopy = pitchSensorValue;
  volumeSensorValueCopy = volumeSensorValue;
  interrupts();
 
  if(millis() - last_time >= 1000) {
    Serial.print("Proc = ");
    Serial.print(AudioProcessorUsage());
    Serial.print(" (");    
    Serial.print(AudioProcessorUsageMax());
    Serial.print("),  Mem = ");
    Serial.print(AudioMemoryUsage());
    Serial.print(" (");    
    Serial.print(AudioMemoryUsageMax());
    Serial.println(")");

    if (ledOn == false) {
      ledOn = true;
    } 
    else {
      ledOn = false;
    }
    digitalWrite(ledPin, ledOn);
    Serial.print("regime = ");
    Serial.println(regime);
    Serial.print("pitchSensorValue = ");
    Serial.println(pitchSensorValueCopy);
    Serial.print("volumeSensorValue = ");
    Serial.println(volumeSensorValueCopy);
    Serial.print("volume = ");
    Serial.println(volume);
  
    last_time = millis();
  }

  float v = volumeSensorValueCopy / 1000000.0 / 2.0;
  if (v <= 0.5) { //You can damadge your ears if you use volume > 0.5
    if (v != volume) {
      codec.volume(v);
    }
    volume = v;
  }
}

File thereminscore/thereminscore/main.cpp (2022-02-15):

#include "mainwindow.h"

#include <QApplication>
#include <QDebug>

#include "pitchandvolumetrack.h"

void testPolyInterpolator() {
    PolyInterpolator solver;
    solver.init(-100.0f, 100.0f, 0.1f, 0.01f);
    solver.start(4, 1, 5.0f, 6.0f, 6.9f);
    solver.end(10, 7.0f, 6.9f, 6.6f);
    for (int i = 4; i <= 12; i++) {
        qDebug("%d\t%f\t%f\t%f", i, solver.eval(i), solver.velocityAt(i), solver.accelerationAt(i));
    }
    qDebug("testPolyInterpolator() test passed");
}

void testPolyInterpolator5() {
    PolyInterpolator solver;
    solver.init(-100.0f, 100.0f, 0.1f, 0.01f);
    IndexedFloats points;
    points.append(IndexedFloat(-5, 10.2f));
    points.append(IndexedFloat(-3, 5.1f));
    points.append(IndexedFloat(-1, 4.0f));
    points.append(IndexedFloat(3, 1.0f));
    points.append(IndexedFloat(7, 3.0f));
    solver.setPoints(points);
    solver.solve();
    for (int i = points.first().index; i <= points.last().index; i++) {
        qDebug("%d\t%f\t%f\t%f", i, solver.eval(i), solver.velocityAt(i), solver.accelerationAt(i));
    }
    qDebug("testPolyInterpolator(5) test passed");
}

void testNoteUtils() {
    for (int i = 0; i < 128; i++) {
        float freq = midiNoteToFrequency((float)i);
        float note = frequencyToMidiNote(freq);
        qDebug("Note %3d\t%9.3f\t%7.3f", i, freq, note);
    }
    for (int db = 0; db <= 120; db++) {
        float gain = dbToGain(db * -1.0);
        float dbf = gainToDb(gain);
        qDebug("-%2d dB:\t%.7f\t%.3f\t%.2f", db, gain, dbf, 1.0f/gain);
    }
    qDebug("static const int CENTS_BRIGHTNESS_128[128] = {");
    for (int i = 0; i < 128; i++) {
        float x = (i - 64) / 64.0f * 0.5f;
        float x2 = 1.0f - x*x;
        int n = static_cast<int>(x2 * 255.5f);
        qDebug("    %d, // %d : %.4f", n, i, x2);
    }
}

int main(int argc, char *argv[])
{
    testPolyInterpolator();
    testPolyInterpolator5();
//    testCubeSolver();
    qDebug("};");
    QApplication a(argc, argv);
    MainWindow w;
    w.show();
    return a.exec();
}

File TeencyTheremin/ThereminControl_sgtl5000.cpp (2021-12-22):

/* Audio Library for Teensy 3.X
 * Copyright (c) 2014, Paul Stoffregen, paul@pjrc.com
 *
 * Development of this audio library was funded by PJRC.COM, LLC by sales of
 * Teensy and Audio Adaptor boards.  Please support PJRC's efforts to develop
 * open source software by purchasing Teensy or other PJRC products.
 *
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
 * THE SOFTWARE IS PROVIDED "AS IS", WITHOUT WARRANTY OF ANY KIND, EXPRESS OR
 * IMPLIED, INCLUDING BUT NOT LIMITED TO THE WARRANTIES OF MERCHANTABILITY,
 * FITNESS FOR A PARTICULAR PURPOSE AND NONINFRINGEMENT. IN NO EVENT SHALL THE
 * AUTHORS OR COPYRIGHT HOLDERS BE LIABLE FOR ANY CLAIM, DAMAGES OR OTHER
 * LIABILITY, WHETHER IN AN ACTION OF CONTRACT, TORT OR OTHERWISE, ARISING FROM,
 * OUT OF OR IN CONNECTION WITH THE SOFTWARE OR THE USE OR OTHER DEALINGS IN
 * THE SOFTWARE.
 */

#include <Arduino.h>
#include "ThereminControl_sgtl5000.h"
#include "Wire.h"

#define CHIP_ID				0x0000
// 15:8 PARTID		0xA0 - 8 bit identifier for SGTL5000
// 7:0  REVID		0x00 - revision number for SGTL5000.

#define CHIP_DIG_POWER			0x0002
// 6	ADC_POWERUP	1=Enable, 0=disable the ADC block, both digital & analog,
// 5	DAC_POWERUP	1=Enable, 0=disable the DAC block, both analog and digital
// 4	DAP_POWERUP	1=Enable, 0=disable the DAP block
// 1	I2S_OUT_POWERUP	1=Enable, 0=disable the I2S data output
// 0	I2S_IN_POWERUP	1=Enable, 0=disable the I2S data input

#define CHIP_CLK_CTRL			0x0004
// 5:4	RATE_MODE	Sets the sample rate mode. MCLK_FREQ is still specified
//			relative to the rate in SYS_FS
//				0x0 = SYS_FS specifies the rate
//				0x1 = Rate is 1/2 of the SYS_FS rate
//				0x2 = Rate is 1/4 of the SYS_FS rate
//				0x3 = Rate is 1/6 of the SYS_FS rate
// 3:2	SYS_FS		Sets the internal system sample rate (default=2)
//				0x0 = 32 kHz
//				0x1 = 44.1 kHz
//				0x2 = 48 kHz
//				0x3 = 96 kHz
// 1:0	MCLK_FREQ	Identifies incoming SYS_MCLK frequency and if the PLL should be used
//				0x0 = 256*Fs
//				0x1 = 384*Fs
//				0x2 = 512*Fs
//				0x3 = Use PLL
//				The 0x3 (Use PLL) setting must be used if the SYS_MCLK is not
//				a standard multiple of Fs (256, 384, or 512). This setting can
//				also be used if SYS_MCLK is a standard multiple of Fs.
//				Before this field is set to 0x3 (Use PLL), the PLL must be
//				powered up by setting CHIP_ANA_POWER->PLL_POWERUP and
//				CHIP_ANA_POWER->VCOAMP_POWERUP.  Also, the PLL dividers must
//				be calculated based on the external MCLK rate and
//				CHIP_PLL_CTRL register must be set (see CHIP_PLL_CTRL register
//				description details on how to calculate the divisors).

#define CHIP_I2S_CTRL			0x0006
// 8	SCLKFREQ	Sets frequency of I2S_SCLK when in master mode (MS=1). When in slave
//			mode (MS=0), this field must be set appropriately to match SCLK input
//			rate.
//				0x0 = 64Fs
//				0x1 = 32Fs - Not supported for RJ mode (I2S_MODE = 1)
// 7	MS		Configures master or slave of I2S_LRCLK and I2S_SCLK.
//				0x0 = Slave: I2S_LRCLK an I2S_SCLK are inputs
//				0x1 = Master: I2S_LRCLK and I2S_SCLK are outputs
//				NOTE: If the PLL is used (CHIP_CLK_CTRL->MCLK_FREQ==0x3),
//				the SGTL5000 must be a master of the I2S port (MS==1)
// 6	SCLK_INV	Sets the edge that data (input and output) is clocked in on for I2S_SCLK
//				0x0 = data is valid on rising edge of I2S_SCLK
//				0x1 = data is valid on falling edge of I2S_SCLK
// 5:4	DLEN		I2S data length (default=1)
//				0x0 = 32 bits (only valid when SCLKFREQ=0),
//					not valid for Right Justified Mode
//				0x1 = 24 bits (only valid when SCLKFREQ=0)
//				0x2 = 20 bits
//				0x3 = 16 bits
// 3:2	I2S_MODE	Sets the mode for the I2S port
//				0x0 = I2S mode or Left Justified (Use LRALIGN to select)
//				0x1 = Right Justified Mode
//				0x2 = PCM Format A/B
//				0x3 = RESERVED
// 1	LRALIGN		I2S_LRCLK Alignment to data word. Not used for Right Justified mode
//				0x0 = Data word starts 1 I2S_SCLK delay after I2S_LRCLK
//					transition (I2S format, PCM format A)
//				0x1 = Data word starts after I2S_LRCLK transition (left
//					justified format, PCM format B)
// 0	LRPOL		I2S_LRCLK Polarity when data is presented.
//				0x0 = I2S_LRCLK = 0 - Left, 1 - Right
//				1x0 = I2S_LRCLK = 0 - Right, 1 - Left
//				The left subframe should be presented first regardless of
//				the setting of LRPOL.

#define CHIP_SSS_CTRL			0x000A
// 14	DAP_MIX_LRSWAP	DAP Mixer Input Swap
//				0x0 = Normal Operation
//				0x1 = Left and Right channels for the DAP MIXER Input are swapped.
// 13	DAP_LRSWAP	DAP Mixer Input Swap
//				0x0 = Normal Operation
//				0x1 = Left and Right channels for the DAP Input are swapped
// 12	DAC_LRSWAP	DAC Input Swap
//				0x0 = Normal Operation
//				0x1 = Left and Right channels for the DAC are swapped
// 10	I2S_LRSWAP	I2S_DOUT Swap
//				0x0 = Normal Operation
//				0x1 = Left and Right channels for the I2S_DOUT are swapped
// 9:8	DAP_MIX_SELECT	Select data source for DAP mixer
//				0x0 = ADC
//				0x1 = I2S_IN
//				0x2 = Reserved
//				0x3 = Reserved
// 7:6	DAP_SELECT	Select data source for DAP
//				0x0 = ADC
//				0x1 = I2S_IN
//				0x2 = Reserved
//				0x3 = Reserved
// 5:4	DAC_SELECT	Select data source for DAC (default=1)
//				0x0 = ADC
//				0x1 = I2S_IN
//				0x2 = Reserved
//				0x3 = DAP
// 1:0	I2S_SELECT	Select data source for I2S_DOUT
//				0x0 = ADC
//				0x1 = I2S_IN
//				0x2 = Reserved
//				0x3 = DAP

#define CHIP_ADCDAC_CTRL		0x000E
// 13	VOL_BUSY_DAC_RIGHT Volume Busy DAC Right
//				0x0 = Ready
//				0x1 = Busy - This indicates the channel has not reached its
//					programmed volume/mute level
// 12	VOL_BUSY_DAC_LEFT  Volume Busy DAC Left
//				0x0 = Ready
//				0x1 = Busy - This indicates the channel has not reached its
//					programmed volume/mute level
// 9	VOL_RAMP_EN	Volume Ramp Enable (default=1)
//				0x0 = Disables volume ramp. New volume settings take immediate
//					effect without a ramp
//				0x1 = Enables volume ramp
//				This field affects DAC_VOL. The volume ramp effects both
//				volume settings and mute When set to 1 a soft mute is enabled.
// 8	VOL_EXPO_RAMP	Exponential Volume Ramp Enable
//				0x0 = Linear ramp over top 4 volume octaves
//				0x1 = Exponential ramp over full volume range
//				This bit only takes effect if VOL_RAMP_EN is 1.
// 3	DAC_MUTE_RIGHT	DAC Right Mute (default=1)
//				0x0 = Unmute
//				0x1 = Muted
//				If VOL_RAMP_EN = 1, this is a soft mute.
// 2	DAC_MUTE_LEFT	DAC Left Mute (default=1)
//				0x0 = Unmute
//				0x1 = Muted
//				If VOL_RAMP_EN = 1, this is a soft mute.
// 1	ADC_HPF_FREEZE	ADC High Pass Filter Freeze
//				0x0 = Normal operation
//				0x1 = Freeze the ADC high-pass filter offset register.  The
//				offset continues to be subtracted from the ADC data stream.
// 0	ADC_HPF_BYPASS	ADC High Pass Filter Bypass
//				0x0 = Normal operation
//				0x1 = Bypassed and offset not updated
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

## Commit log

2021-09-15 current sensing comparator sensor simulation
2021-09-15 main board kicad project and geerber files
    [teensy41_main_board.kicad_pcb, teensy41_main_board.sch]
2021-09-16 add dester's bjt current sensing oscillator model
2021-09-24 opamp models, pll schematic
2021-09-27 current sensing pll model
2021-10-11 current sensing oscillator model
2021-10-12 current sensing oscillator ltspice model 04
2021-10-13 current sensing oscillator 05
2021-10-15 display and controls board
    [teensy41_display_controls.kicad_pcb, teensy41_display_controls.sch]
2021-10-27 dual opamp current sensing oscillator - ltspice model
2021-10-28 current sensing pll ltspice model
2021-11-09 spice model - unbuffered inverters current sensing oscillator
2021-11-12 current sensing oscillator on inverters and bjt current mirrors - ltspice model
2021-11-23 xo2 / tinyfpga ax2 theremin sensor implementation - initial commit
2021-11-30 teensy fpga main board fpga project
    [teensy41_fpga_theremin.kicad_pcb, teensy41_fpga_theremin.sch]
2021-11-30 kicad libraries
2021-12-09 cabinet OpenSCAD - part 1
    [cabinet_assembled.scad, cabinet_bottom.scad, cabinet_front.scad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]
2021-12-09 teensy fpga theremin main pcb
    [teensy41_fpga_theremin.kicad_pcb, teensy41_fpga_theremin.sch]
2021-12-13 openscad cabinet project
    [cabinet_assembled.scad, cabinet_tablet_mount.scad, pitch_antenna.scad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]
2021-12-14 cabinet design - openscad
    [cabinet_assembled.scad, cabinet_bottom.scad, cabinet_front.scad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]
2021-12-16 Initial commit
    A modified PlaySynthMusic example. Testing sound and codec. Prints audio chip id to serial port.
2021-12-17 cabinet openscad model:
    [cabinet_assembled.scad, cabinet_bottom.scad, cabinet_params.scad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]
2021-12-17 Pitch and volume input simulation added
    Using IntervalTimer to simulate pitch and volume input from sensors. Volume control now works. Sensor values are printed to serial port.
2021-12-24 cabinet model
    [cabinet_assembled.scad, cabinet_bottom.scad, cabinet_front.scad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]
2021-12-24 teensytheremin fpga main board kicad project
    [teensy41_fpga_theremin.kicad_pcb, teensy41_fpga_theremin.sch]
2022-01-10 cabinet opanscad model
    [cabinet_assembled.scad, cabinet_laser_cut.scad, cabinet_params.scad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]
2022-01-10 cabinet model openscad fixes
    [cabinet_assembled.scad, cabinet_laser_cut.scad, cabinet_side.scad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]
2022-01-11 update preadme; convert pcb schematic to KiCAD 6.0
    [teensy41_fpga_theremin.kicad_pcb, teensy41_fpga_theremin.kicad_sch]
2022-01-11 cabinet - added program tact button
    [cabinet_assembled.scad, theremin_pcb.scad]
2023-03-01 analog front end spice model - DDS current sensing
2023-03-01 dds sine drive phase shift sensor ltspice simulation results
    [dds_current_sensing_phase_shift_afe_ltspice_model_simulation.xlsx]
2023-03-14 wallin oscillator BJTs diff cascade power rails sensing LTSpice model
2023-03-17 wallin oscillator on bjt differential amp with current mirror load
2023-03-19 current sensing oscillator ltspice model
2023-03-22 current sensing theremin oscillator - voltage follower buffer - ltspice model
2023-03-22 voltage follower current sensing buffer - ltspice model:
2023-04-04 OTA volt follower buffer ltspice model
2023-04-15 ltspice model of 2 x OTA current sensing oscillator
